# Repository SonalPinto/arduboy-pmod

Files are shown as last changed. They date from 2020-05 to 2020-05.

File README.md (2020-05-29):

# Arduboy PMOD

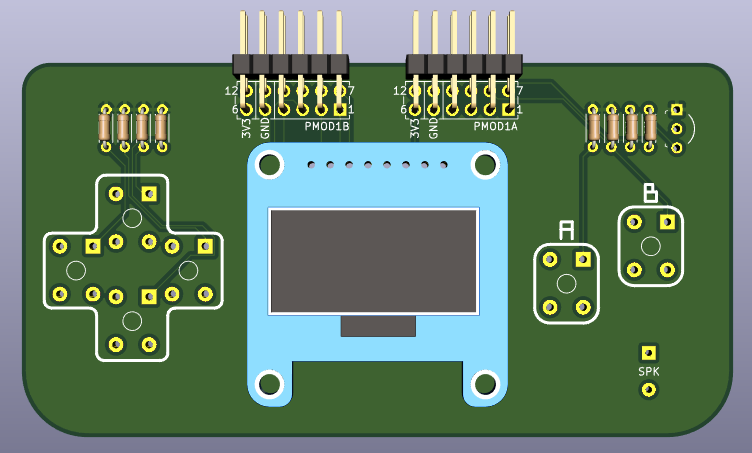
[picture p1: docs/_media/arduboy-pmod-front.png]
Arduboy PMOD Front


A simple dual PMOD connector board using thru-hole components on a 2-layer PCB. It was designed for playing the Arduboy on the [iCEBreaker FPGA Board](https://1bitsquared.com/products/icebreaker), but is generic enough for other creative purposes.

# Hardware Specifications

* Adafruit monochrome [1.3" 128x64 OLED](https://www.adafruit.com/product/938).
* Six 6x6mm Tactile switches. I prefer feel of the [B3F-1020](https://www.digikey.com/product-detail/en/omron-electronics-inc-emc-div/B3F-1020/SW402-ND/44059) with 100gf actuation. 10K pull down resistors for each button.
* Small Piezo speaker (like [this one](https://www.digikey.com/product-detail/en/tdk-corporation/PS1240P02CT3/445-5229-1-ND/2179635) or [this](https://www.digikey.com/product-detail/en/murata-electronics/PKM13EPYH4000-A0/490-4698-1-ND/1219329)). A [C1815 transistor](https://www.digikey.com/product-detail/en/on-semiconductor/KSC1815YTA/KSC1815YTACT-ND/3908203) and two 1K resistors for driving it.
* Generic 100mil 6x2 angled male headers like [these](https://www.digikey.com/product-detail/en/sullins-connector-solutions/PREC006DBAN-M71RC/S2112EC-06-ND/2775648) (12 position, 2 rows), for the PMOD connectors.
* The resistors are 1/8W (the distance between the pads is 200mil), instead of the bigger 1/4W ones. Links: [1K](https://www.digikey.com/product-detail/en/stackpole-electronics-inc/CF18JT1K00/CF18JT1K00CT-ND/2022742), [10K](https://www.digikey.com/product-detail/en/stackpole-electronics-inc/CF18JT10K0/CF18JT10K0CT-ND/2022766).

# Ordering

[v0.1 hosted on OSHPark](https://oshpark.com/shared_projects/jLNBtxrI)

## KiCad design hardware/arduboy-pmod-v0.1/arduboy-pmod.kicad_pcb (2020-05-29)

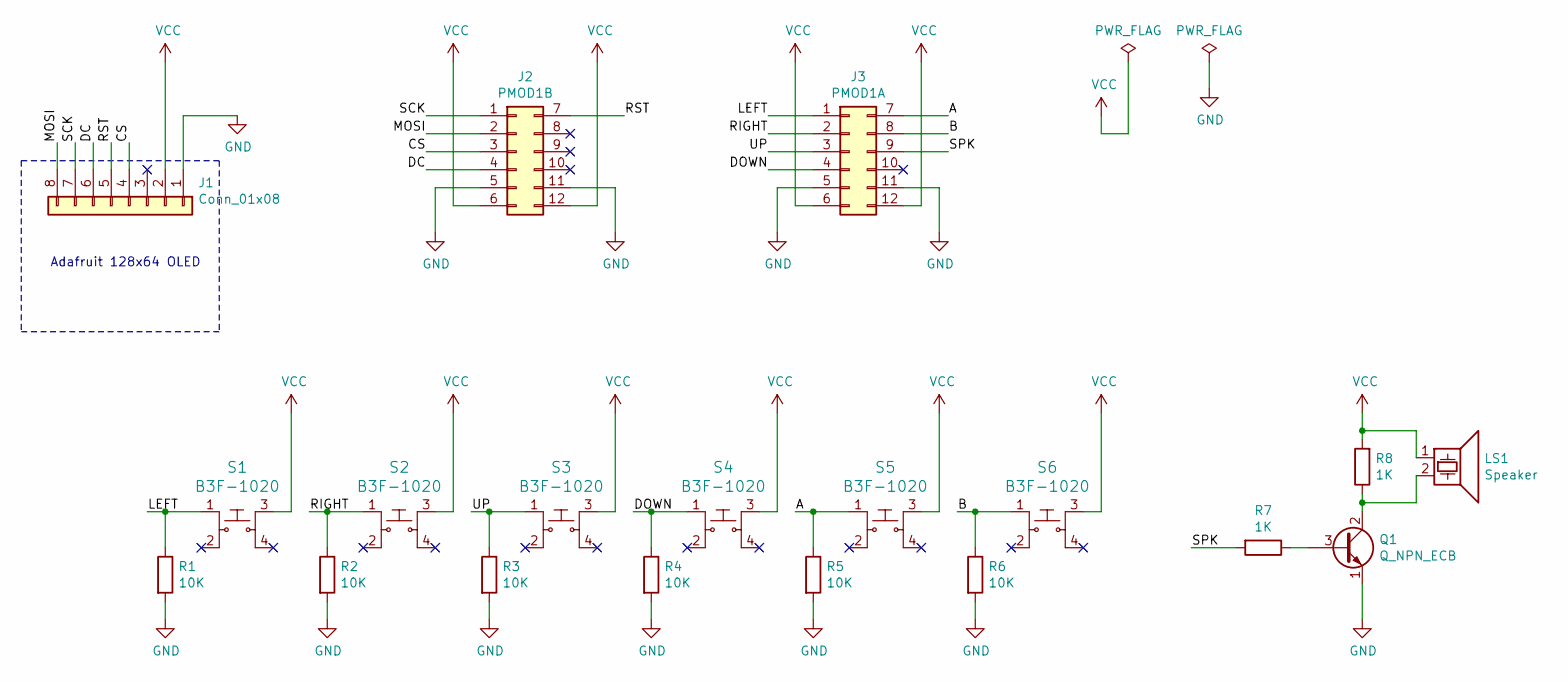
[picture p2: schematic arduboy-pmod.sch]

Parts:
J1: Conn_01x08; Adafruit_SSD1306
J2: PMOD1B; PMODHeader_2x6_2.54mm_Horizontal_Mirrored
J3: PMOD1A; PMODHeader_2x6_2.54mm_Horizontal_Mirrored
LS1: Speaker; Piezo_Transducer_THT_PS1240P02BT
Q1: Q_NPN_ECB; TO-92-3_Formed_Leads
R1, R2, R3, R4, R5, R6: 10K; R_Axial_DIN0204_L3.6mm_D1.6mm_P5.08mm_Horizontal
R7, R8: 1K; R_Axial_DIN0204_L3.6mm_D1.6mm_P5.08mm_Horizontal
S1, S2, S3, S4, S5, S6: B3F-1020; Switch_Tactile_THT_B3F-1xxx_nosilk; MPN B3F-1000; Digi-Key_PN SW400-ND

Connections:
/A: J3.7, R5.1, S5.1
/B: J3.8, R6.1, S6.1
/CS: J1.4, J2.3
/DC: J1.6, J2.4
/DOWN: J3.4, R4.1, S4.1
/LEFT: J3.1, R1.1, S1.1
/MOSI: J1.8, J2.2
/RIGHT: J3.2, R2.1, S2.1
/RST: J1.5, J2.7
/SCK: J1.7, J2.1
/SPK: J3.9, R7.2
/UP: J3.3, R3.1, S3.1
GND: J1.1, J2.5, J2.11, J3.5, J3.11, Q1.1 (E), R1.2, R2.2, R3.2, R4.2, R5.2, R6.2
unnamed: LS1.2, Q1.2 (C), R8.1
unnamed: Q1.3 (B), R7.1
VCC: J1.2, J2.6, J2.12, J3.6, J3.12, LS1.1, R8.2, S1.3, S2.3, S3.3, S4.3, S5.3, S6.3

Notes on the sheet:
Adafruit 128x64 OLED

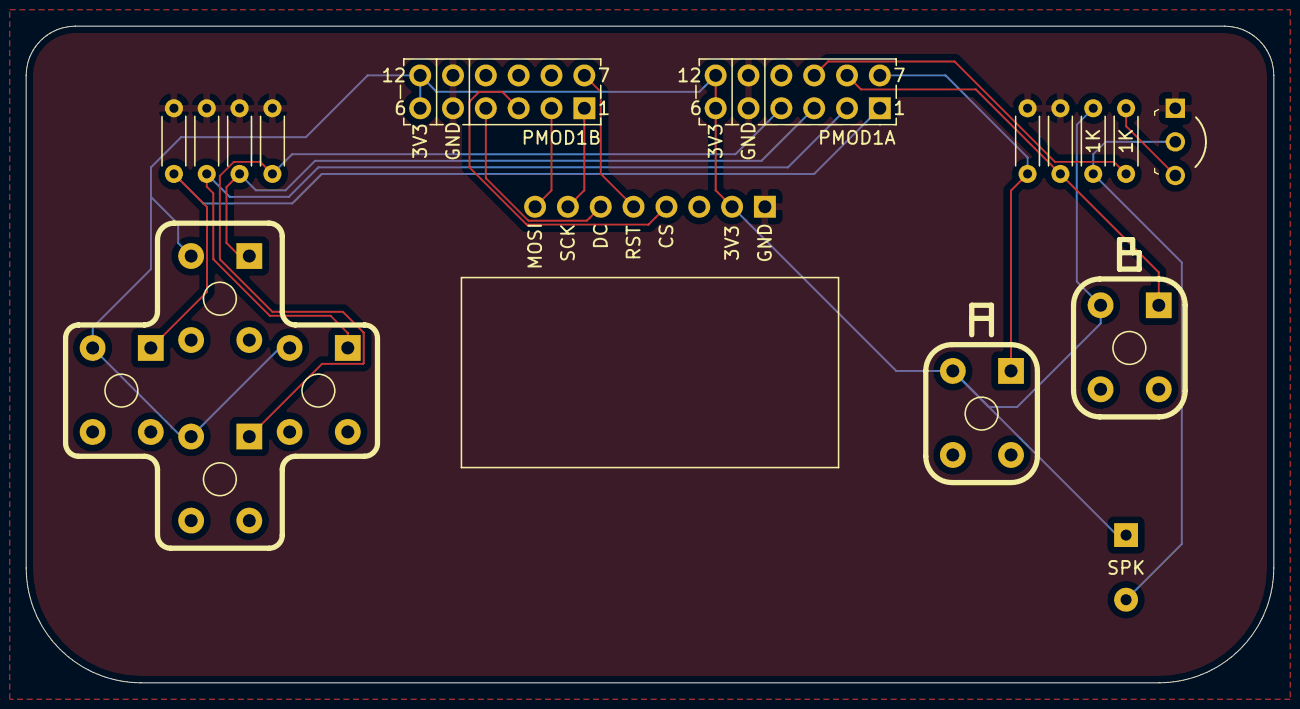
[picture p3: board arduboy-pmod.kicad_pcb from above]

Board: 2 copper layers, 96.5 x 50.8 mm, 19 parts (0 on the bottom side), 16 nets.

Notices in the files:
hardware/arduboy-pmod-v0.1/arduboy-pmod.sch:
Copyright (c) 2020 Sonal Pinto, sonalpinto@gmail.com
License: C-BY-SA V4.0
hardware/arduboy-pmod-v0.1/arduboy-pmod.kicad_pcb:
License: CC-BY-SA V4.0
